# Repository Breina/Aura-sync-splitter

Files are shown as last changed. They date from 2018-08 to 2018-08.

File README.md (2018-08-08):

Aura sync splitter
===

Purpose
---
This schematic can be used for when one wants to use the an addressable WS2811B signal to power additional RGB components separately. These component groups will have their own dedicated PSU connection.

Setup
---
Include the `WS2811.lbr` library as a library in Eagle. This is the DIP8 version of the WS2811 IC.

Requirements
---
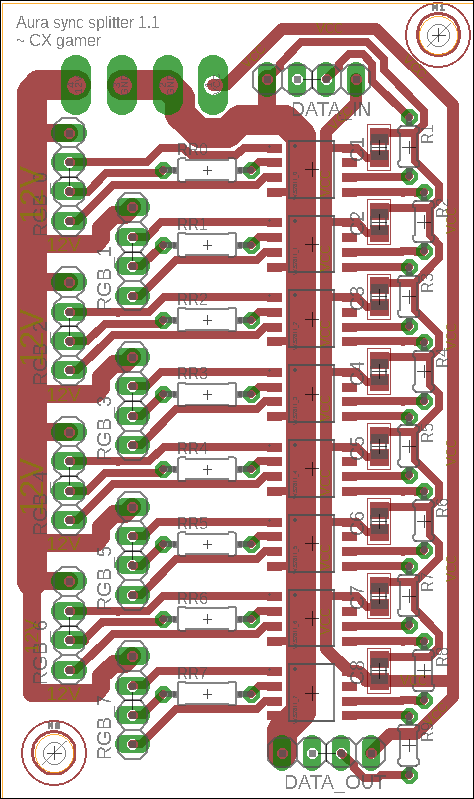
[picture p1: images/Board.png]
Board


This board was made in Eagle, so it's a requirement to do anything with the source files. As for hardware, for one board, one needs:
* 8x WS2811 IC's, DIP8 format
* 9x 2.54 mm groups of 4 round pins.
* 9x 33 Ω resistors (R1 - R9) used to prevent reflection and hot-swap.
* 8x 100 nF capacitors used as bypass.
* Every connected component requires an additional resistor (RR0 - RR7). A 330 Ω  resistor should do, but these can be calculated as described in the included WS2811 datasheet, page 5.
* For easy connecting, a 4-pin male molex connection would be handy.

Usage
---
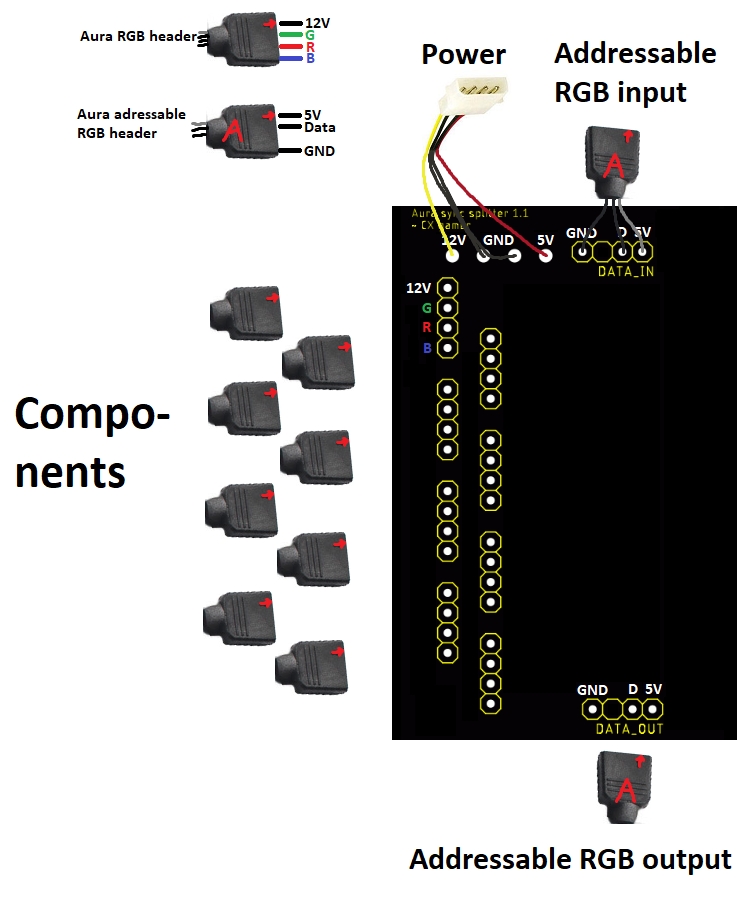
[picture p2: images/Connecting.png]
Connecting


After everything is soldered, the 8 ports can be used to connect Aura Sync headers. The DATA_IN pins are to be connected to the motherboard's addressable LED pins and The molex goes to the PSU.

If more RGB is desired, one can use the DATA_OUT to chain these boards or to use the addressable RGB signal to a final component.

WARNING: Do not make mistakes. The two kinds of Aura headers are exactly the same, mixing them up may cause component failure. Triple check the PSU cables as well and measure the voltages before connecting the motherboard. Wrongly connecting those may damage your motherboard.

Known issues
---
* Aura sync headers are a little larger than there is room for on the board. One can safely sand away a little bit of plastic to make it fit.
* Some addressable RGB headers don't have a hole for a dummy PIN. If using 4 PINs at the DATA_OUT header, you can safely remove the unused one (2nd from the left).

Versions
---
1.1: Fixed the color PIN order. ASUS uses the WS2811B which uses GRB instead of our WS2811's RGB. Also made some more room to solder the resistor.
1.0: Initial version

Disclaimer
---
Use at your own risk. If anything breaks, one only has himself to blame.

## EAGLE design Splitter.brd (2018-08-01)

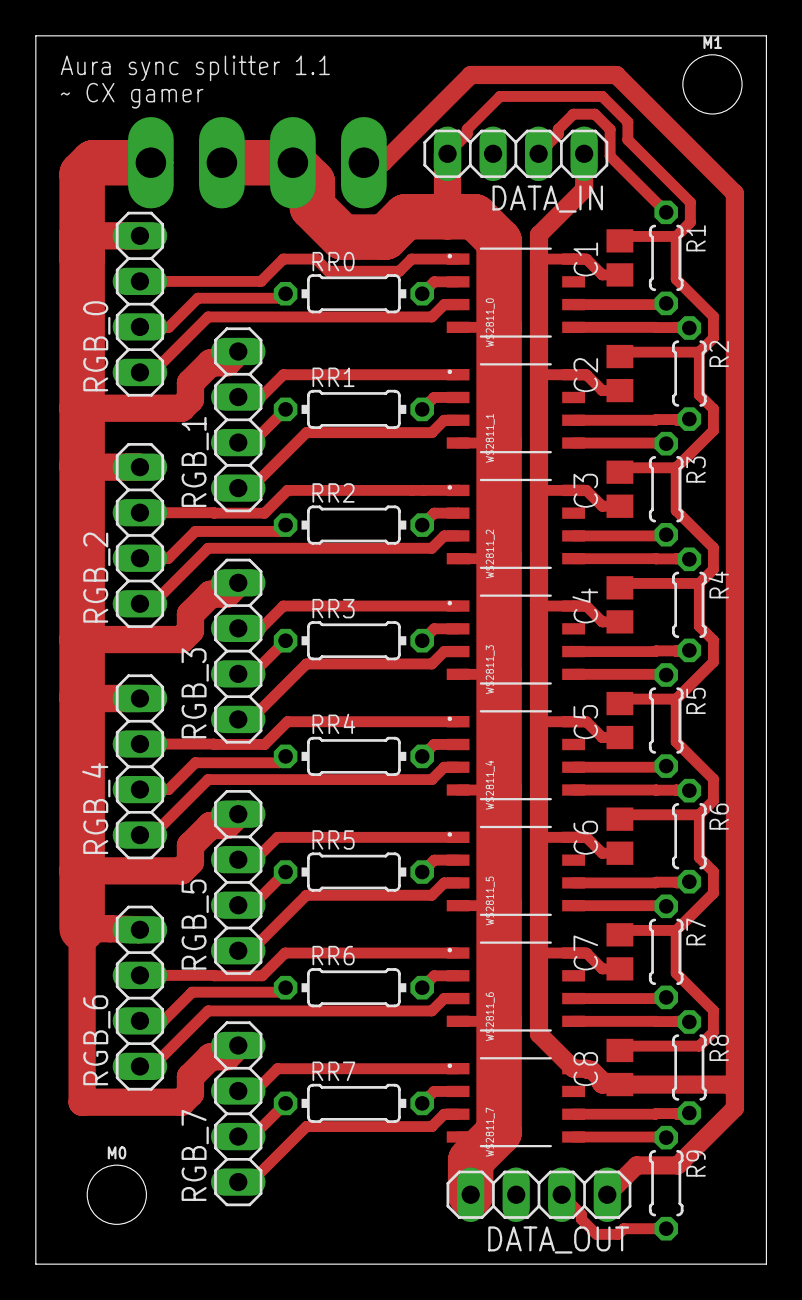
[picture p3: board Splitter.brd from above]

Board: 2 copper layers, 40.7 x 68.5 mm, 46 parts (1 on the bottom side), 53 nets.

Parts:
C1, C2, C3, C4, C5, C6, C7, C8: 100nF; C0805
DATA_IN: DATA_IN; 1X04
DATA_OUT: DATA_OUT; 1X04
M0, M1: STAND-OFF
POWER: POWER; KK-156-4
R1, R2, R3, R4, R5, R6, R7, R8, R9: 33; 0204/5
RGB_0: RGB_0; 1X04
RGB_1: RGB_1; 1X04
RGB_2: RGB_2; 1X04
RGB_3: RGB_3; 1X04
RGB_4: RGB_4; 1X04
RGB_5: RGB_5; 1X04
RGB_6: RGB_6; 1X04
RGB_7: RGB_7; 1X04
RR0, RR1, RR2, RR3, RR4, RR5, RR6, RR7: 0204/7
WS2811_0: WS2811_0; WS2811
WS2811_1: WS2811_1; WS2811
WS2811_2: WS2811_2; WS2811
WS2811_3: WS2811_3; WS2811
WS2811_4: WS2811_4; WS2811
WS2811_5: WS2811_5; WS2811
WS2811_6: WS2811_6; WS2811
WS2811_7: WS2811_7; WS2811

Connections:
12V: POWER.4, RGB_0.4, RGB_1.4, RGB_2.4, RGB_3.4, RGB_4.4, RGB_5.4, RGB_6.4, RGB_7.4
+5V: R8.2, WS2811_7.DIN
B0: RGB_0.1, WS2811_0.OUTB
B1: RGB_1.1, WS2811_1.OUTB
B2: RGB_2.1, WS2811_2.OUTB
B3: RGB_3.1, WS2811_3.OUTB
B4: RGB_4.1, WS2811_4.OUTB
B5: RGB_5.1, WS2811_5.OUTB
B6: RGB_6.1, WS2811_6.OUTB
B7: RGB_7.1, WS2811_7.OUTB
DO: DATA_OUT.2, R9.2
G0: RGB_0.3, WS2811_0.OUTR
G1: RGB_1.3, WS2811_1.OUTR
G2: RGB_2.3, WS2811_2.OUTR
G3: RGB_3.3, WS2811_3.OUTR
G4: RGB_4.3, WS2811_4.OUTR
G5: RGB_5.3, WS2811_5.OUTR
G6: RGB_6.3, WS2811_6.OUTR
G7: RGB_7.3, WS2811_7.OUTR
GND: C1.2, C2.2, C3.2, C4.2, C5.2, C6.2, C7.2, C8.2, DATA_IN.4, DATA_OUT.4, POWER.2, POWER.3, WS2811_0.GND, WS2811_1.GND, WS2811_2.GND, WS2811_3.GND, WS2811_4.GND, WS2811_5.GND, WS2811_6.GND, WS2811_7.GND
unnamed: R9.1, WS2811_7.DO
unnamed: R2.1, WS2811_0.DO
unnamed: R3.1, WS2811_1.DO
unnamed: R2.2, WS2811_1.DIN
unnamed: R4.1, WS2811_2.DO
unnamed: R6.1, WS2811_4.DO
unnamed: R3.2, WS2811_2.DIN
unnamed: R7.1, WS2811_5.DO
unnamed: R8.1, WS2811_6.DO
unnamed: R4.2, WS2811_3.DIN
unnamed: R5.1, WS2811_3.DO
unnamed: R5.2, WS2811_4.DIN
unnamed: R6.2, WS2811_5.DIN
unnamed: DATA_IN.2, R1.1
unnamed: R7.2, WS2811_6.DIN
R0: RGB_0.2, RR0.1
R1: RGB_1.2, RR1.1
R2: RGB_2.2, RR2.1
R3: RGB_3.2, RR3.1
R4: RGB_4.2, RR4.1
R5: RGB_5.2, RR5.1
R6: RGB_6.2, RR6.1
R7: RGB_7.2, RR7.1
S$4: R1.2, WS2811_0.DIN
S$5: RR0.2, WS2811_0.OUTG
S$6: RR2.2, WS2811_2.OUTG
S$7: RR3.2, WS2811_3.OUTG
S$9: RR1.2, WS2811_1.OUTG
S$10: RR4.2, WS2811_4.OUTG
S$11: RR5.2, WS2811_5.OUTG
S$13: RR6.2, WS2811_6.OUTG
S$14: RR7.2, WS2811_7.OUTG
VCC: C1.1, C2.1, C3.1, C4.1, C5.1, C6.1, C7.1, C8.1, DATA_IN.1, DATA_OUT.1, POWER.1, WS2811_0.VDD, WS2811_1.VDD, WS2811_2.VDD, WS2811_3.VDD, WS2811_4.VDD, WS2811_5.VDD, WS2811_6.VDD, WS2811_7.VDD

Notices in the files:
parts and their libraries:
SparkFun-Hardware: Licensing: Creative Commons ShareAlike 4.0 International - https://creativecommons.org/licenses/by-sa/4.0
